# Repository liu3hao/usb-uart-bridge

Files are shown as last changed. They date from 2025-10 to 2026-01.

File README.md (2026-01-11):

# Compact CH340 USB-C USB-UART bridge
This repository contains the files for a compact USB-C to UART bridge using the CH340 chip. The main purpose is to create a compact dev board that can be used for UART communications.

## Project files
1. Schematics - designed with [circuitscript](https://circuitscript.net)
2. PCB layout - designed with [KiCad](https://www.kicad.org/)

## Production
The initial production was done with [JLCPCB](https://jlcpcb.com/) and parts are completely sourced from LCSC.

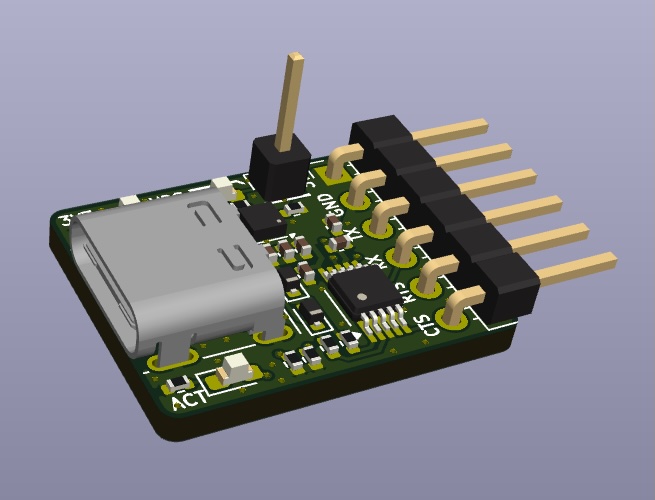
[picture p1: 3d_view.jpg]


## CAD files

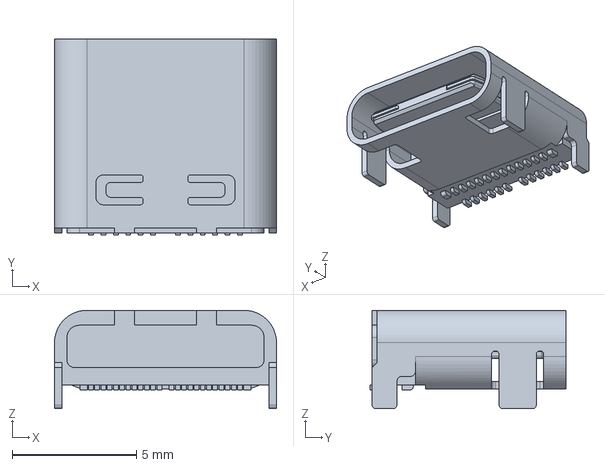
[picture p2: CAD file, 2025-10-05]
1054500101.stp
8.94 x 7.90 x 3.96 mm

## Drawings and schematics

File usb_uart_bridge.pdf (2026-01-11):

31 2 D4

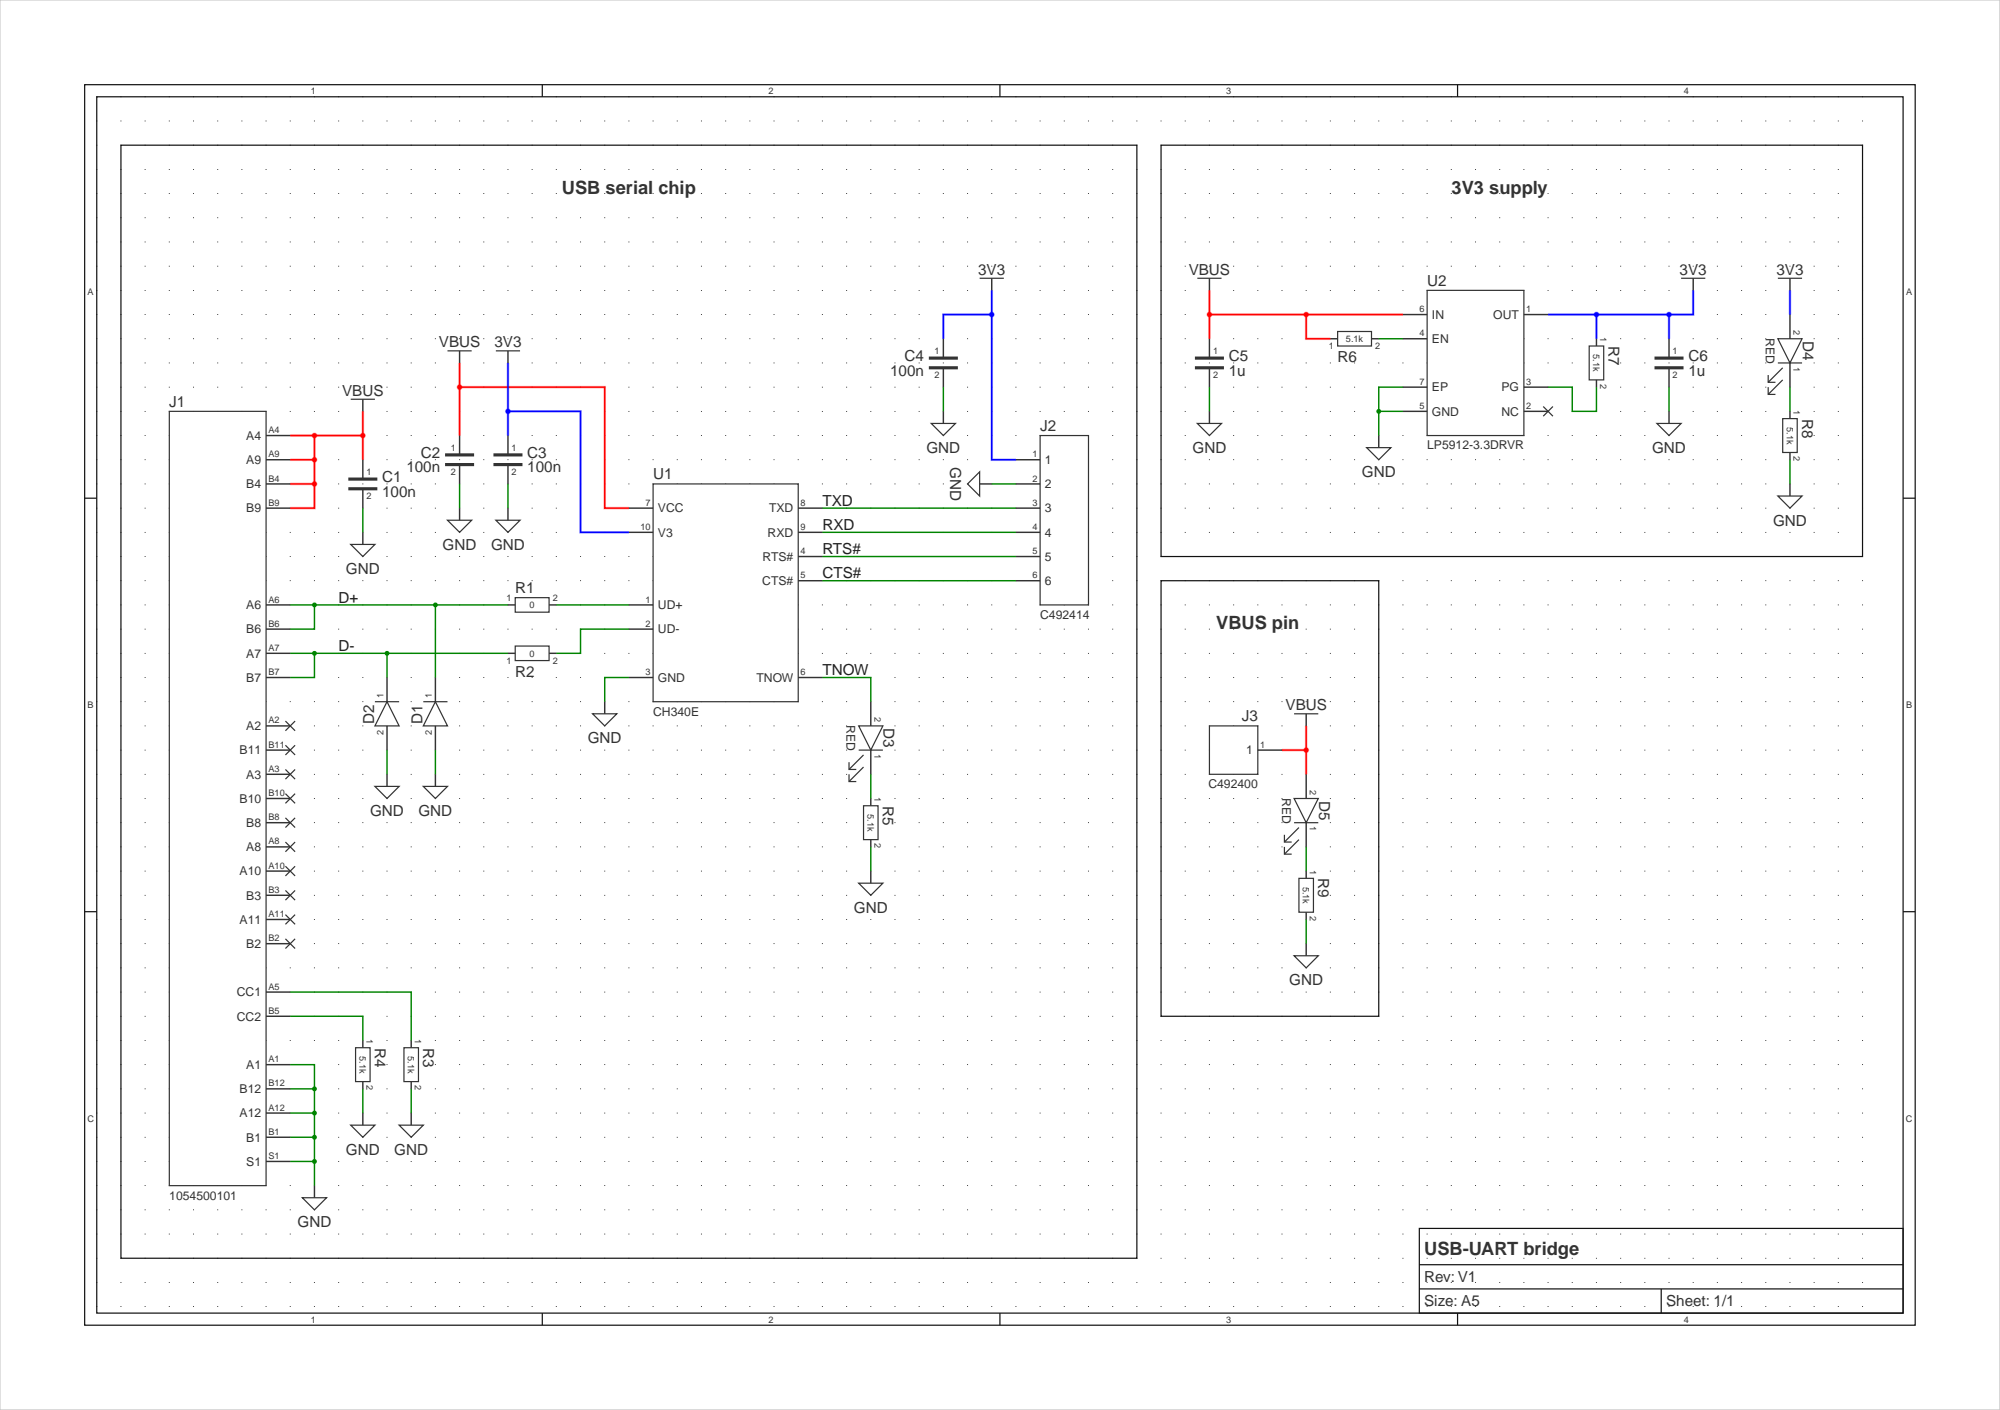
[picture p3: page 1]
DGND; RED

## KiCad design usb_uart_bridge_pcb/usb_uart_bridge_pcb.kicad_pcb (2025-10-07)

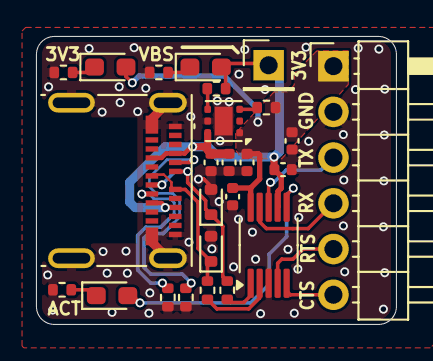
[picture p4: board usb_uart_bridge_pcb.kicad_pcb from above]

Board: 2 copper layers, 20.0 x 16.0 mm, 25 parts (0 on the bottom side), 19 nets.

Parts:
C1, C2, C3, C4: 100n; C_0402_1005Metric
C5, C6: 1u; C_0402_1005Metric
D1, D2: D_SOD-523
D3, D4, D5: LED_0603_1608Metric_Pad1.05x0.95mm_HandSolder
J1: USB_C_Receptacle_Molex_105450-0101
J2: PinHeader_1x06_P2.54mm_Horizontal
J3: PinHeader_1x01_P2.54mm_Vertical
R1, R2: 0; R_0402_1005Metric
R3, R4, R5, R6, R7, R8, R9: 5.1k; R_0402_1005Metric
U1: MSOP-10_3x3mm_P0.5mm
U2: WSON-6-1EP_2x2mm_P0.65mm_EP1x1.6mm_ThermalVias

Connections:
/3V3: C3.1, C4.1, C6.1, D4.2, J2.1, R5.1, U1.10, U2.1
/CTS#: J2.6, U1.5
/D+: D1.1, J1.A6, J1.B6, R1.1
/D-: D2.1, J1.A7, J1.B7, R2.1
/GND: C1.2, C2.2, C3.2, C4.2, C5.2, C6.2, D1.2, D2.2, J1.A1, J1.A12, J1.B1, J1.B12, J1.S1, J2.2, R3.2, R6.2, R7.2, R8.2, R9.2, U1.3, U2.5, U2.7
/NET-(D3-1): D3.1, R3.1
/NET-(D4-1): D4.1, R6.1
/NET-(D5-1): D5.1, R7.1
/NET-(J1-A5): J1.A5, R8.1
/NET-(J1-B5): J1.B5, R9.1
/NET-(R1-2): R1.2, U1.1
/NET-(R2-2): R2.2, U1.2
/NET-(R4-2): R4.2, U2.4
/NET-(R5-2): R5.2, U2.3
/RTS#: J2.5, U1.4
/RXD: J2.4, U1.9
/TNOW: D3.2, U1.6
/TXD: J2.3, U1.8
/VBUS: C1.1, C2.1, C5.1, D5.2, J1.A4, J1.A9, J1.B4, J1.B9, J3.1, R4.1, U1.7, U2.6

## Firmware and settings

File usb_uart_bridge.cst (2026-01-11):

from std import *

document.sheet_type = sheet_A5()

gnd = dgnd()
vbus = supply("VBUS")
v3v3 = supply("3V3")

vbus.color = "red"
vbus.highlight = "red"

v3v3.color = "blue"
v3v3.highlight = "blue"

ch340e = create component:
    pins: 
        1: "UD+"
        2: "UD-"
        3: "GND"
        4: "RTS#"
        5: "CTS#"
        6: "TNOW"
        7: "VCC"
        8: "TXD"
        9: "RXD"
        10: "V3"
    type: "ic"
    arrange:
        left: 7, 10, [2], 1, 2, [1], 3
        right: 8, 9, 4, 5, [3], 6
    width: 600
    params:
        mpn: "CH340E"
        LCSC_part: "C99652"
        footprint: "Package_SO:MSOP-10_3x3mm_P0.5mm"

usb_conn = create component:
    pins:
        A1:  "A1"
        A2:  "A2"
        A3:  "A3"
        A4:  "A4"
        A5:  "CC1"
        A6:  "A6"
        A7:  "A7"
        A8:  "A8"
        A9:  "A9"
        A10: "A10"
        A11: "A11"
        A12: "A12"

        B1:  "B1"
        B2:  "B2"
        B3:  "B3"
        B4:  "B4"
        B5:  "CC2"
        B6:  "B6"
        B7:  "B7"
        B8:  "B8"
        B9:  "B9"
        B10: "B10"
        B11: "B11"
        B12: "B12"

        S1: "S1"

    arrange:
        right: "A4", "A9", "B4", "B9", [3], "A6", "B6", "A7", "B7",[1], "A2", "B11", "A3", "B10", "B8", "A8", "A10", "B3", "A11", "B2", [1], "A5", "B5", [1], "A1", "B12", "A12", "B1", "S1"
    params:
        mpn: "1054500101"
        manufacturer: "MOLEX"
        LCSC_part: "C134092"
        footprint: "Connector_USB:USB_C_Receptacle_Molex_105450-0101"

connheader_6pins = create component:
    pins: 6
    arrange:
        left: 1,2,3,4,5,6
    width: 200
    params:
        footprint: "Connector_PinHeader_2.54mm:PinHeader_1x06_P2.54mm_Horizontal"
        LCSC_part: "C492414"
        mpn: "C492414"

connheader_1pin = create component:
    pins: 1
    arrange:
        left: 1
    width: 200
    params:
        footprint: "Connector_PinHeader_2.54mm:PinHeader_1x01_P2.54mm_Vertical"
        LCSC_part: "C492400"
        mpn: "C492400"


lp5912 = create component:
    pins: 
        1: "OUT"
        2: "NC"
        3: "PG"
        4: "EN"
        5: "GND"
        6: "IN"
        7: "EP"
    type: "ic"
    arrange:
        left: 6, 4, [1], 7, 5
        right: 1, [2], 3, 2
    params:
        mpn: "LP5912-3.3DRVR"
        LCSC_part: "C524780"
        footprint: "Package_SON:WSON-6-1EP_2x2mm_P0.65mm_EP1x1.6mm_ThermalVias"

def esd_diode():
    width = 100
    height = 100

    # Diode is drawn horizontally
    #  -|>|-
    return create component:
        pins: 2
        type: "diode"
        display: create graphic (params):
            triangle: -width/2, 0, width/2, 0, height
            vline: width/2, -height/2, height
            hpin: 2, -width/2-100, 0, 100    # anode
            hpin: 1, width/2 + 100, 0, -100  # cathode
            label: params.refdes, 0, -100, fontSize=50, anchor="middle", vanchor="top"
        params:
            footprint: "Diode_SMD:D_SOD-523"
            mpn: "ESD5B5.0ST1G"
            LCSC_part: "C93623"

sheet:
    ..title = "USB-UART bridge"
    ..revision = "V1"


    frame:
        ..title = "USB serial chip"

        at usb_conn: #= J1  
            "A4":
                wire right 100
                branch:
                    wire right 200 

                    branch:
                        wire down 100
                        add cap(100n) #= C1 
                        wire down 100
                        to gnd

                    wire up 100
                    to vbus

                wire down 100
                branch:
                    wire auto to pin "A9"
                wire down 100
                branch:
                    wire auto to pin "B4"

                wire down 100 auto to pin "B9"

            "A1":
                wire right 100 down 100

                branch:
                    wire auto to pin "B12"
                wire down 100

                branch:
                    wire auto to pin "A12"

                wire down 100
                branch:
                    wire auto to pin "B1"

                wire down 100
                branch:
                    wire auto to pin "S1"
                
                wire down 100
                to gnd
        
            "A6":
                wire right 100
                branch:
                    wire auto
                    to pin "B6"
                wire right 100
                add label("D+")
                wire right 400
                branch:
                    wire down 300
                    add esd_diode() #= D1 
                    wire down 100
                    to gnd

                wire right 300
                add res(0) #= R1 
                wire right 300
                to ch340e pin "UD+" #= U1 

            "A7":
                wire right 100
                branch:
                    wire auto
                    to pin "B7"
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

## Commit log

2025-10-05 1. initial commit
    [1054500101.stp, usb_uart_bridge_pcb.kicad_pcb, usb_uart_bridge_pcb.kicad_sch]
2025-10-07 1. fixed missing 5.1K resistors
    [usb_uart_bridge_pcb.kicad_pcb]
2026-01-11 1.added README and output schematic in pdf format
